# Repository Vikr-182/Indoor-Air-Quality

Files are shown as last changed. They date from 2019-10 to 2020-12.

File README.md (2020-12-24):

# Indoor-Air-Quality-Management
A complete Air Quality Index (AQI) sensing and management system designed and deployed in houses, to analyze the effects of outdoor and indoor events on indoor air quality, along with a Twitter service for constant updates.

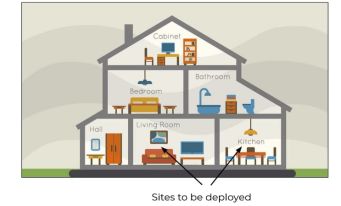
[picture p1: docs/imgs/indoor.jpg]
House Image


## Components Involved
We list one by one, all the components involved in the usage -
- Using Microcontroller ESP8266
- Designing the 3D Enclosure
- Collecting and Analyzing Data
- Twitter Alerts
- OneM2M Usage

## Desigining the case
We designed the enclosure for our model using Autodesk Fusion360 and 3D printed it at Product Labs, IIITH.
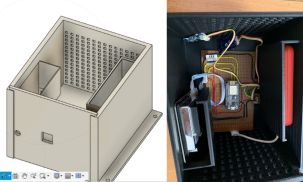
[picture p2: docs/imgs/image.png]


## Collecting and Analyzing Data
- We were able to accurately predict the cooking times after carefully looking at the data - 
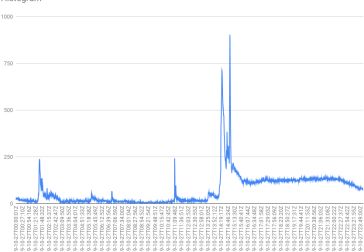
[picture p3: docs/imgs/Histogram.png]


Notice the spike, which is representative of the cooking period in the kitchen.
- We specially collected our data during the Diwali festival and noticed anomalies in the data - 
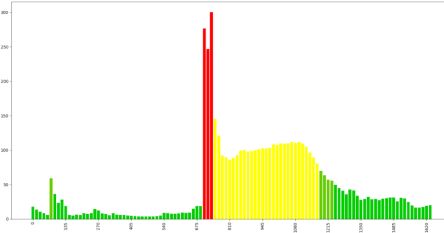
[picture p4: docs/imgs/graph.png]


Notice the read peak and slight normalization after due process.

## Twitter Alerts
Frequent time-to-time alerts were issued at this account [here](https://twitter.com/iiith_indoor). 

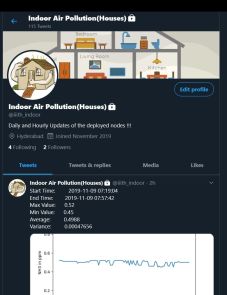
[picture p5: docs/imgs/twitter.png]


## OneM2M Usage
OneM2M was used as a common container for holding data and servicing REST APIs to and from.
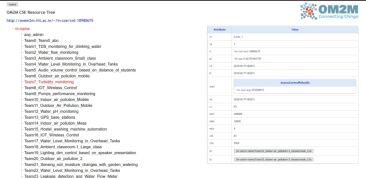
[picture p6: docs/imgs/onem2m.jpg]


## Software Used
- The following software were used in our project and will be required to successfully replicate our product -
```
Arduino IDE>=1.7 - Used for microcontrollers.
MATLAB ThingSpeak - IoT data visualization platform.
Autodesk Fusion360 - For editing and visualizing CAD models.
EaglePCB - For desigining and exporting PCB.
```
- Apart from the above, please include all the sensor libraries provided in the `src/sensor_libraries.zip`. Refer [here](https://www.arduino.cc/en/guide/libraries) for the tutorial for installation in the Arduino IDE.
- To install the python libaries, please use the command 
```
$: pip install --user -r requirements.txt
```

Created by - 
Bhavyajeet Singh, Pranav Kirsur and Vikrant Dewangan

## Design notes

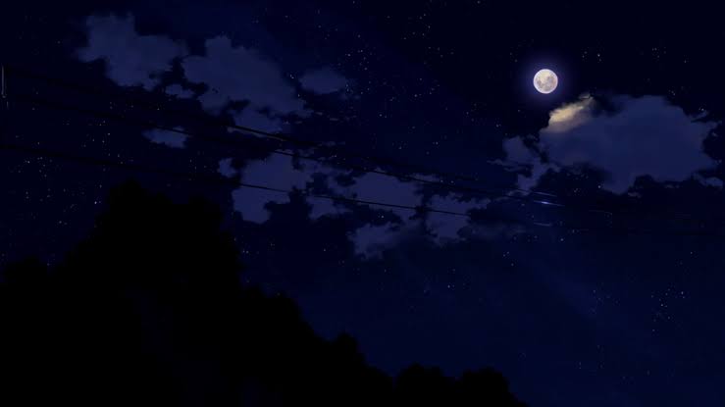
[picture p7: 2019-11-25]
tweet/imgs/night.jpeg

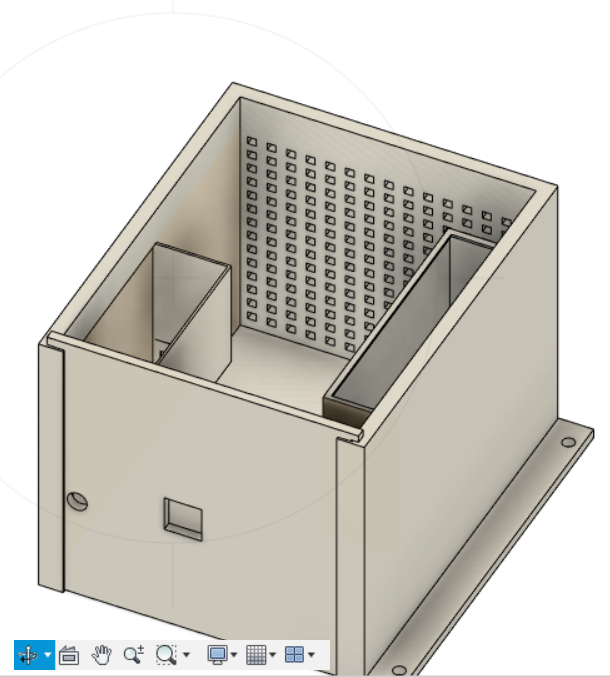
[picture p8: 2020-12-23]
docs/imgs/model_cad.png

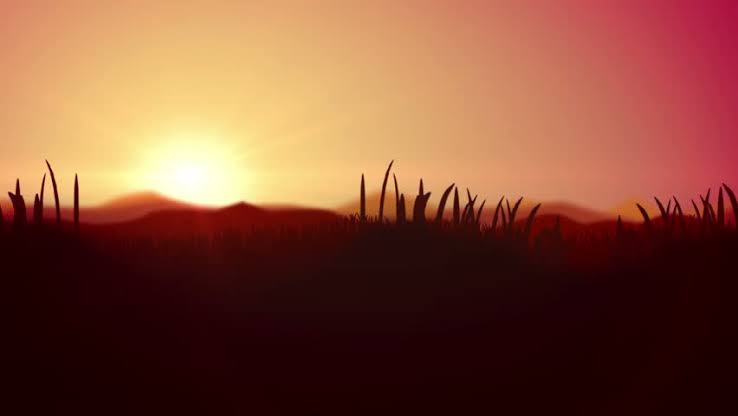
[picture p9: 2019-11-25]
tweet/imgs/dawn.jpeg

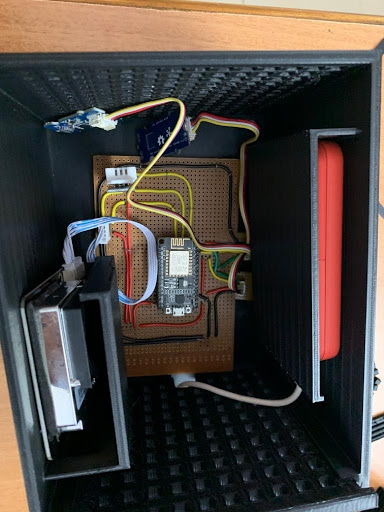
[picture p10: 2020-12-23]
docs/imgs/casing.jpg

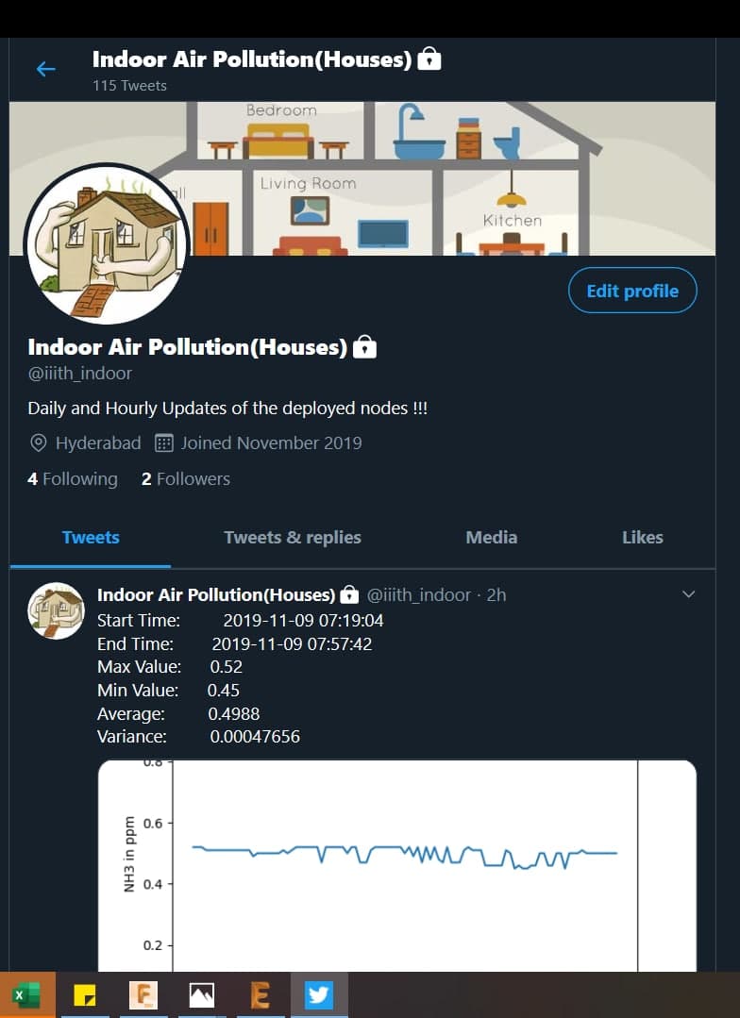
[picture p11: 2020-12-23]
docs/imgs/twitter.jpg

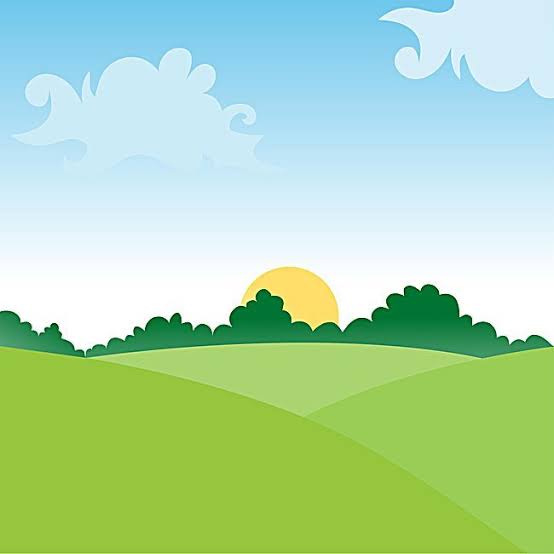
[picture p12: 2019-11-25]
tweet/imgs/morning.jpeg

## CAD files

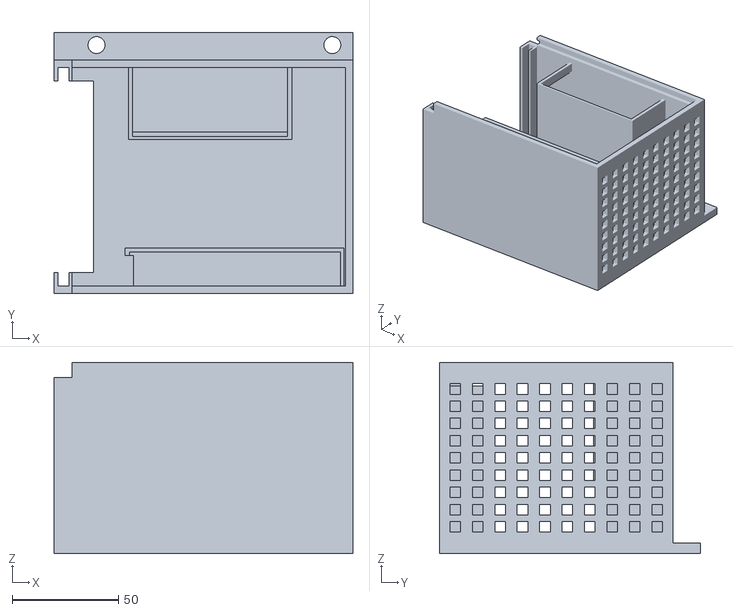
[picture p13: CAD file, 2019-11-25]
models/cad_models/Casing.stl
140.7 x 123.0 x 90.0

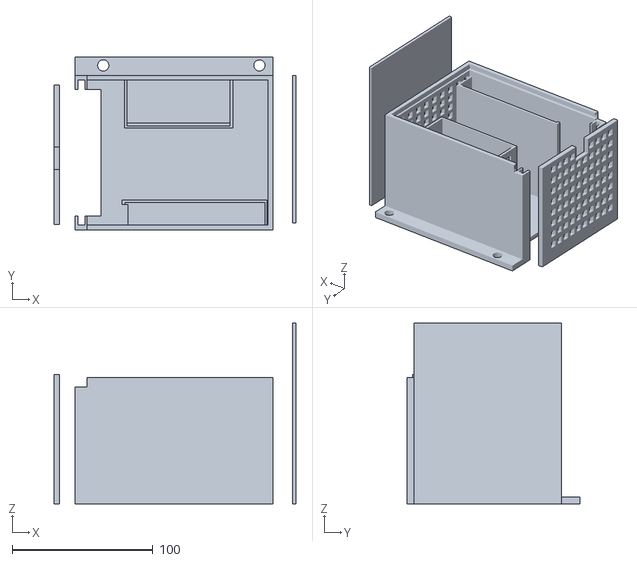
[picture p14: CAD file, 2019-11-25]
models/cad_models/Optimised design v6.stl
172.0 x 123.0 x 128.5

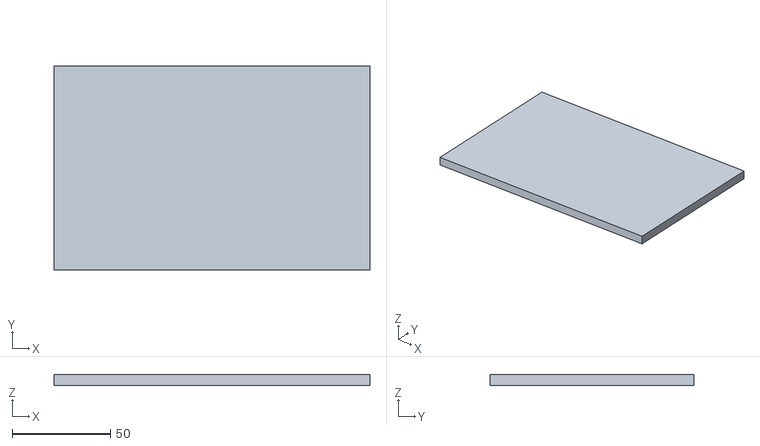
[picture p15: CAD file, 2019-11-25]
models/cad_models/Lid_final_final.stl
161.1 x 104.0 x 5.50

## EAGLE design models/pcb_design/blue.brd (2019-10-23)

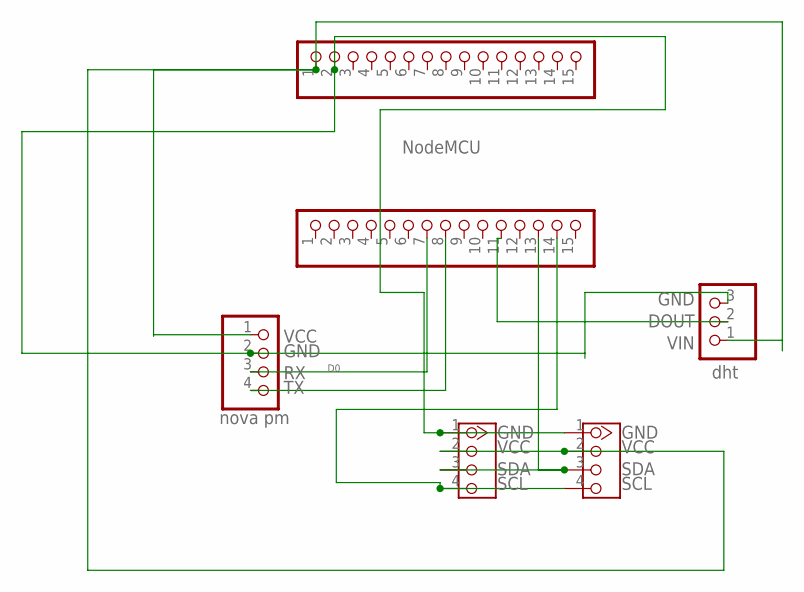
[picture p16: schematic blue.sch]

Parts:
J1, J2: 4P-2.0; HW4-2.0
JP1, JP2: PINHD-1X15; 1X15
JP3: PINHD-1X3; 1X03
JP4: PINHD-1X4; 1X04

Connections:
unnamed: JP1.11, JP3.2
unnamed: JP1.8, JP4.4
unnamed: JP1.7, JP4.3
unnamed: J1.2, J2.2, JP2.1, JP3.1, JP4.1
unnamed: J1.4, J2.4, JP1.14
unnamed: J1.3, J2.3, JP1.13
unnamed: J1.1, J2.1, JP2.2, JP3.3, JP4.2

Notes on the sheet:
dht
SCL
SDA
VCC
GND
VIN
DOUT
NodeMCU
nova pm

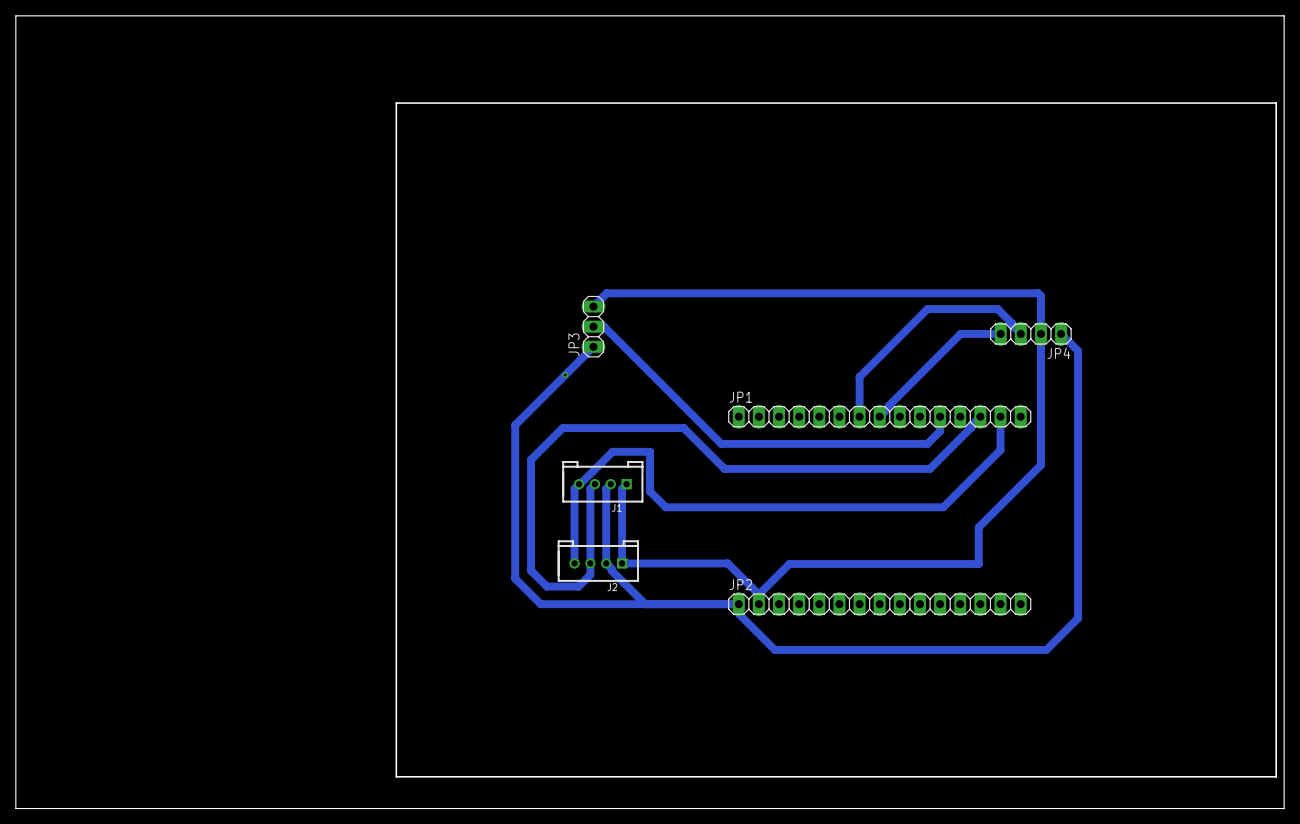
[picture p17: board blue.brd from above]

Board: 2 copper layers, 160.0 x 100.0 mm, 6 parts (0 on the bottom side), 7 nets.

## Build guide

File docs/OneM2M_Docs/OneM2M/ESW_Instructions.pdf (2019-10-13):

# Instructions

1. Download and run OM2M server
Go to this link http://wiki.eclipse.org/OM2M/Download
You have to download Version 1.3.0 from the Official release.\ Follow the instructions to start the One M2m server.
Then start the OM2M server.
2. Hotspot Wifi Process
a. First create a hotspot with your mobile and connect your laptop with it.
b. Change your arduino credentials (SSID, Password and Server IP Address(Your Laptop’s IP address)) accordingly.
3. Choose the file based on whether you have Node MCU or ESP32 Your file name will be TX_Nodemcu or TX_esp32 accordingly.
4. If your teams ae has a container named MEET_TA_ASAP contact any of the OneM2M TAs(Suraj, Salil or Faizan) otherwise if you are getting Node_1 as a container then you can go rig up the circuit and make sure that data transfer is happening.
5. Once you are able to send data to the server, let the TAs know for further instructions.

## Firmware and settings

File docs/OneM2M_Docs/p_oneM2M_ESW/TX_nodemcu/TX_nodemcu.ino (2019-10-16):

#include <JSONVar.h>
#include <Arduino_JSON.h>
#include <JSON.h>

#include <ESP8266WiFi.h>
#include <SoftwareSerial.h>

#include <Adafruit_Sensor.h>
#include <DHT.h>
#include <DHT_U.h>

#define DHTPIN 2     // Digital pin connected to the DHT sensor 

#define DHTTYPE DHT11     // DHT 11

DHT_Unified dht(DHTPIN, DHTTYPE);

uint32_t delayMS;


// ##################### Update the Wifi SSID, Password and IP adress of the server ##########
// WIFI params
char* WIFI_SSID = "adarsh-iot"; 
char* WIFI_PSWD = "adarsh1996";

String CSE_IP      = "10.42.0.36";
// #######################################################

int WIFI_DELAY  = 100; //ms

// oneM2M : CSE params
int   CSE_HTTP_PORT = 8080;
String CSE_NAME    = "in-name";
String CSE_M2M_ORIGIN  = "admin:admin";

// oneM2M : resources' params
String DESC_CNT_NAME = "DESCRIPTOR";
String DATA_CNT_NAME = "DATA";
String CMND_CNT_NAME = "COMMAND";
int TY_AE  = 2;
int TY_CNT = 3;
int TY_CI  = 4;
int TY_SUB = 23;

// HTTP constants
int LOCAL_PORT = 9999;
char* HTTP_CREATED = "HTTP/1.1 201 Created";
char* HTTP_OK    = "HTTP/1.1 200 OK\r\n";
int REQUEST_TIME_OUT = 5000; //ms

//MISC
int LED_PIN   = D1;
int SERIAL_SPEED  = 9600;

#define DEBUG

///////////////////////////////////////////




// Global variables
WiFiServer server(LOCAL_PORT);    // HTTP Server (over WiFi). Binded to listen on LOCAL_PORT contant
WiFiClient client;
String context = "";
String command = "";        // The received command



// Method for creating an HTTP POST with preconfigured oneM2M headers
// param : url  --> the url path of the targted oneM2M resource on the remote CSE
// param : ty --> content-type being sent over this POST request (2 for ae, 3 for cnt, etc.)
// param : rep  --> the representaton of the resource in JSON format
String doPOST(String url, int ty, String rep) {

  String postRequest = String() + "POST " + url + " HTTP/1.1\r\n" +
                       "Host: " + CSE_IP + ":" + CSE_HTTP_PORT + "\r\n" +
                       "X-M2M-Origin: " + CSE_M2M_ORIGIN + "\r\n" +
                       "Content-Type: application/json;ty=" + ty + "\r\n" +
                       "Content-Length: " + rep.length() + "\r\n"
                       "Connection: close\r\n\n" +
                       rep;

  // Connect to the CSE address

  Serial.println("connecting to " + CSE_IP + ":" + CSE_HTTP_PORT + " ...");

  // Get a client
  WiFiClient client;
  if (!client.connect(CSE_IP, CSE_HTTP_PORT)) {
    Serial.println("Connection failed !");
    return "error";
  }

  // if connection succeeds, we show the request to be send
#ifdef DEBUG
  Serial.println(postRequest);
#endif

  // Send the HTTP POST request
  client.print(postRequest);

  // Manage a timeout
  unsigned long startTime = millis();
  while (client.available() == 0) {
    if (millis() - startTime > REQUEST_TIME_OUT) {
      Serial.println("Client Timeout");
      client.stop();
      return "error";
    }
  }

  // If success, Read the HTTP response
  String result = "";
  if (client.available()) {
    result = client.readStringUntil('\r');
    //    Serial.println(result);
  }
  while (client.available()) {
    String line = client.readStringUntil('\r');
    Serial.print(line);
  }
  Serial.println();
  Serial.println("closing connection...");
  return result;
}

// Method for creating an ApplicationEntity(AE) resource on the remote CSE (this is done by sending a POST request)
// param : ae --> the AE name (should be unique under the remote CSE)
String createAE(String ae) {
  String aeRepresentation =
    "{\"m2m:ae\": {"
    "\"rn\":\"" + ae + "\","
    "\"api\":\"org.demo." + ae + "\","
    "\"rr\":\"true\","
    "\"poa\":[\"http://" + WiFi.localIP().toString() + ":" + LOCAL_PORT + "/" + ae + "\"]"
    "}}";
#ifdef DEBUG
  Serial.println(aeRepresentation);
#endif
  return doPOST("/" + CSE_NAME, TY_AE, aeRepresentation);
}

// Method for creating an Container(CNT) resource on the remote CSE under a specific AE (this is done by sending a POST request)
// param : ae --> the targeted AE name (should be unique under the remote CSE)
// param : cnt  --> the CNT name to be created under this AE (should be unique under this AE)
String createCNT(String ae, String cnt) {
  String cntRepresentation =
    "{\"m2m:cnt\": {"
    "\"rn\":\"" + cnt + "\","
    "\"min\":\"" + -1 + "\""
    "}}";
  return doPOST("/" + CSE_NAME + "/" + ae, TY_CNT, cntRepresentation);
}

// Method for creating an ContentInstance(CI) resource on the remote CSE under a specific CNT (this is done by sending a POST request)
// param : ae --> the targted AE name (should be unique under the remote CSE)
// param : cnt  --> the targeted CNT name (should be unique under this AE)
// param : ciContent --> the CI content (not the name, we don't give a name for ContentInstances)
String createCI(String ae, String cnt, String ciContent) {
  String ciRepresentation =
    "{\"m2m:cin\": {"
    "\"con\":\"" + ciContent + "\""
    "}}";
  return doPOST("/" + CSE_NAME + "/" + ae + "/" + cnt, TY_CI, ciRepresentation);
}


// Method for creating an Subscription (SUB) resource on the remote CSE (this is done by sending a POST request)
// param : ae --> The AE name under which the SUB will be created .(should be unique under the remote CSE)
//          The SUB resource will be created under the COMMAND container more precisely.
String createSUB(String ae) {
  String subRepresentation =
    "{\"m2m:sub\": {"
    "\"rn\":\"SUB_" + ae + "\","
    "\"nu\":[\"" + CSE_NAME + "/" + ae  + "\"], "
    "\"nct\":1"
    "}}";
  return doPOST("/" + CSE_NAME + "/" + ae + "/" + CMND_CNT_NAME, TY_SUB, subRepresentation);
}


// Method to register a module (i.e. sensor or actuator) on a remote oneM2M CSE
void registerModule(String module, bool isActuator, String intialDescription, String initialData) {
  if (WiFi.status() == WL_CONNECTED) {
    String result;
    // 1. Create the ApplicationEntity (AE) for this sensor
    result = createAE(module);
    if (result == HTTP_CREATED) {
#ifdef DEBUG
      Serial.println("AE " + module + " created  !");
#endif

      // 2. Create a first container (CNT) to store the description(s) of the sensor
      result = createCNT(module, DESC_CNT_NAME);
      if (result == HTTP_CREATED) {
#ifdef DEBUG
        Serial.println("CNT " + module + "/" + DESC_CNT_NAME + " created  !");
#endif


        // Create a first description under this container in the form of a ContentInstance (CI)
        result = createCI(module, DESC_CNT_NAME, intialDescription);
        if (result == HTTP_CREATED) {
#ifdef DEBUG
          Serial.println("CI " + module + "/" + DESC_CNT_NAME + "/{initial_description} created !");
#endif
        }
      }

      // 3. Create a second container (CNT) to store the data  of the sensor
      result = createCNT(module, DATA_CNT_NAME);
      if (result == HTTP_CREATED) {
#ifdef DEBUG
        Serial.println("CNT " + module + "/" + DATA_CNT_NAME + " created !");
#endif

        // Create a first data value under this container in the form of a ContentInstance (CI)
        result = createCI(module, DATA_CNT_NAME, initialData);
        if (result == HTTP_CREATED) {
#ifdef DEBUG
          Serial.println("CI " + module + "/" + DATA_CNT_NAME + "/{initial_aata} created !");
#endif
        }
      }

      // 3. if the module is an actuator, create a third container (CNT) to store the received commands
      if (isActuator) {
        result = createCNT(module, CMND_CNT_NAME);
        if (result == HTTP_CREATED) {
#ifdef DEBUG
          Serial.println("CNT " + module + "/" + CMND_CNT_NAME + " created !");
#endif

          // subscribe to any ne command put in this container
          result = createSUB(module);
          if (result == HTTP_CREATED) {
#ifdef DEBUG
            Serial.println("SUB " + module + "/" + CMND_CNT_NAME + "/SUB_" + module + " created !");
#endif
          }
        }
      }
    }
  }
}


void init_WiFi() {
  Serial.println("Connecting to  " + String(WIFI_SSID) + " ...");
  WiFi.persistent(false);
  WiFi.begin(WIFI_SSID, WIFI_PSWD);

  // wait until the device is connected to the wifi network
  while (WiFi.status() != WL_CONNECTED) {
    delay(WIFI_DELAY);
    Serial.print(".");
  }

  // Connected, show the obtained ip address
  Serial.println("WiFi Connected ==> IP Address = " + WiFi.localIP().toString());
}

void init_HTTPServer() {
  server.begin();
  Serial.println("Local HTTP Server started !");
}

void task_HTTPServer() {
  // Check if a client is connected
  client = server.available();
  if (!client)
    return;

  // Wait until the client sends some data
  Serial.println("New client connected. Receiving request... ");
  while (!client.available()) {
#ifdef DEBUG_MODE
    Serial.print(".");
#endif
    delay(5);
  }

  // Read the request
  String request = client.readString();
  Serial.println(request);
  client.flush();



  int start, end;
  // identify the right module (sensor or actuator) that received the notification
  // the URL used is ip:port/ae
  start = request.indexOf("/");
  end = request.indexOf("HTTP") - 1;
  context = request.substring(start + 1, end);
#ifdef DEBUG
  Serial.println(String() + start + " , " + end + " -> " + context + ".");
#endif


  // ingore verification messages
  if (request.indexOf("vrq") > 0) {
    client.flush();
    return;
  }


  //Parse the request and identify the requested command from the device
  //Request should be like "[operation_name]"
  start = request.indexOf("[");
  end = request.indexOf("]"); // first occurence of
  command = request.substring(start + 1, end);
#ifdef DEBUG
  Serial.println(String() + start + " , " + end + " -> " + command + ".");
#endif

  client.flush();
}

// ######### START OF EXAMPLE ######### //
void init_luminosity() {
  String initialDescription = "Name = LuminositySensor\t"
                              "Unit = Lux\t"
                              "Location = Home\t";
  String initialData = "0";
  registerModule("LuminositySensor", false, initialDescription, initialData);
}

void task_luminosity() {
  int sensorValue;
  int sensorPin = A0;
  sensorValue = analogRead(sensorPin);
  //sensorValue = random(10, 20);
#ifdef DEBUG
  Serial.println("luminosity value = " + sensorValue);
#endif

  String ciContent = String(sensorValue);

  createCI("LuminositySensor", DATA_CNT_NAME, ciContent);
}


void init_led() {
  String initialDescription = "Name = LedActuator\t"
                              "Location = Home\t";
  String initialData = "off";
  registerModule("LedActuator", true, initialDescription, initialData);
}
void task_led() {

}

void command_led(String cmd) {
  //Serial.print(cmd);
  if (cmd == "switchOn") {
#ifdef DEBUG
    Serial.println("Switching on the LED ...");
#endif
    digitalWrite(LED_PIN, LOW);
  }
  else if (cmd == "switchOff") {
#ifdef DEBUG
    Serial.println("Switching off the LED ...");
#endif
    digitalWrite(LED_PIN, HIGH);
  }
}
// ######### END OF EXAMPLE ######### //

/////////////////////////////////////////////////////////////////////////////////

// ######################################################## //
// ######### USE THIS SPACE TO DECLARE VARIABLES  ######### //
// ########################################################  //

float temp, hum;

// ########################################################  //

void setup() {
  // intialize the serial liaison
  Serial.begin(SERIAL_SPEED);

  // Connect to WiFi network
  init_WiFi();

  // Start HTTP server
  init_HTTPServer();

  // ######### USE THIS SPACE FOR YOUR SETUP CODE ######### //

  dht.begin();

  // ###################################################### //

}

// Main loop of the µController
void loop() {
  // ############################################################### //
  // ######### USE THIS SPACE FOR YOUR SENSOR POLING CODE  ######### //
  // ###############################################################  //

  // Get temperature event and print its value.
  sensors_event_t event;
  dht.temperature().getEvent(&event);
  if (isnan(event.temperature))
  {
    Serial.println(F("Error reading temperature!"));
  }
  else
  {
    Serial.print(F("Temperature: "));
    Serial.print(event.temperature);
    temp = event.temperature;
    Serial.println(F("°C"));
  }

  // Get humidity event and print its value.
  dht.humidity().getEvent(&event);
  if (isnan(event.relative_humidity))
  {
    Serial.println(F("Error reading humidity!"));
  }
  else
  {
    Serial.print(F("Humidity: "));
    Serial.print(event.relative_humidity);
    hum = event.relative_humidity;
    Serial.println(F("%"));
  }

  // ######################################################### //




  // ################################################################### //
  // ######### USE THIS SPACE FOR YOUR SENDING DATA TO SERVER  ######### //
  // ################################################################### //

  /*
      CreateCI(AE_NAME,CONTAINER_NAME,SENSOR_VALUE)

      CreateCI is what posts your sensor data into the container.

      In the below example:
            AE_NAME: Team8_Automated_Driving (As stated in the resource tree)
            CONTAINER_NAME : node_1 ( or as stated in the resource tree)
            SENSOR_VALUE : string of comma separated all sensor values (Eg: 27,25 is temp,hum)
  */

  
  // Storing as a string in a single containers
  String sensor_value_string;
  sensor_value_string = String(temp) + String(",") + String(hum);
  createCI("Team0_abc", "node_1", sensor_value_string);

  // Check if the data instance was created.
  delay(15000); // DO NOT CHANGE THIS VALUE

 
  // ################################################################### //
}

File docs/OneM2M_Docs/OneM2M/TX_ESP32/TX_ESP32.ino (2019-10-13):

#include "WiFi.h"
#include "HTTPClient.h"
#include "ArduinoJson.h"

char* wifi_ssid = "surajHotSpot";
char* wifi_pwd = "onem2mlab";
String cse_ip = "192.168.43.59";
////////////////////////////////////////
//Sensor Setup
//------------------------------------//

#include <DHT.h>
uint8_t DHTPIN = 4;
//our sensor is DHT11 type
#define DHTTYPE DHT11
//create an instance of DHT sensor
DHT dht(DHTPIN, DHTTYPE);

//------------------------------------//

////////////////////////////////////////

StaticJsonBuffer<200> jsonBuffer;
JsonObject& user_data = jsonBuffer.createObject();
JsonObject& temp_user_data = jsonBuffer.createObject();
JsonObject& sensor_data = jsonBuffer.createObject();

String cse_port = "8080";
String server = "http://"+cse_ip+":"+cse_port+"/~/in-cse/in-name/";

String createCI(String server, String ae, String cnt, String val)
{
  HTTPClient http;
  http.begin(server + ae + "/" +cnt);
  http.addHeader("X-M2M-Origin", "admin:admin");
  http.addHeader("Content-Type", "application/json;ty=4");
  int code = http.POST("{\"m2m:cin\": {\"cnf\": \"text/plain:0\",\"con\": " + String(val) + "}}");
  http.end();
  Serial.print(code);
  delay(100);
}

void setup()
{
  Serial.begin(115200);

  // Set WiFi to station mode and disconnect from an AP if it was previously connected
  WiFi.mode(WIFI_STA);
  WiFi.disconnect();
  delay(100);

  WiFi.begin(wifi_ssid, wifi_pwd);

  while (WiFi.status() != WL_CONNECTED) {
    delay(500);
    Serial.println("Connecting to WiFi..");
  }

  Serial.println("Connected to the WiFi network");
  //LED ON CODE INDICATING CONN TO WIFI

  //call begin to start DHT sensor
  pinMode(DHTPIN, INPUT);
  dht.begin();

  Serial.println("Setup done");
}

void loop()
{
  //Serial.print(n);
  //Serial.println(" networks found");

  //Take DHT sensor state
  //float t = 0.2;
  float t = dht.readTemperature();
  Serial.print("Temperature: ");
  Serial.print(t);
  Serial.println("");
  //float h = 0.1;
  float h = dht.readHumidity();
  Serial.print("Humidity: ");
  Serial.print(h);
  Serial.println("");

  //user_data.printTo(Serial);


  //To GET values
  //http.begin("http://192.168.0.113:8080/~/in-cse/in-name/verte001/DATA/la");
  //http.begin("http://192.168.0.113:8080/~/in-cse");
  //int httpCode = http.GET();


  createCI(server, "Team0_abc", "node_1", String(t)+","+String(h));
  //createCI(server, "Team0_abc", "node_1", String(3));
  delay(15000);
}

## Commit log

2019-10-20 added error correction code-backup_test.ino
    [backup_test.ino, test.ino]
2019-10-23 added pcb_design
    [blue.brd, blue.sch, red.brd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]
2019-10-25 added sensor_libraries
2019-11-21 added big codes
    [pm25.csv]
2019-11-21 added extra files
    [x25.csv, y25.csv, zpm25.csv]
2019-11-22 added seperate channelwise tweets
    [x25.csv]
2019-11-25 added latest combined data
    [dht.csv, mics.csv, novaPM.csv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]
2019-11-25 added the casing designs
    [Casing.stl, Lid_final_final.stl, Optimised design v6.stl]
